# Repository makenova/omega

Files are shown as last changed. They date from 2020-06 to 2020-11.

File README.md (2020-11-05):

# Omega

Hot swap
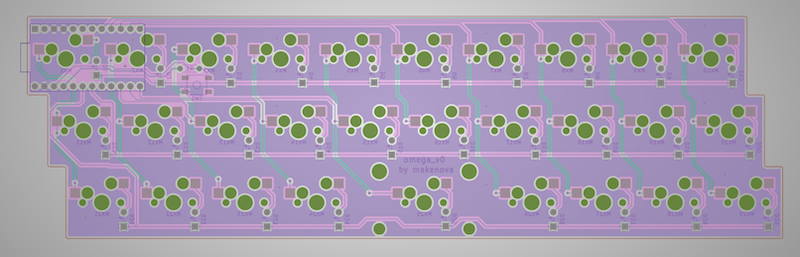
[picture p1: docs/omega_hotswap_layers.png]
tracespace layer


Solder
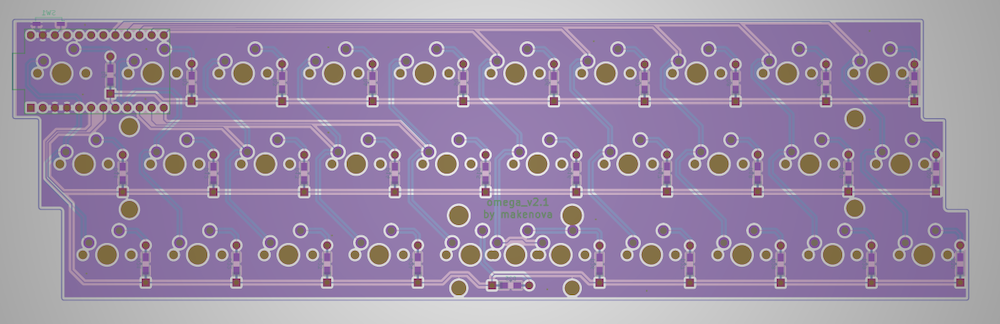
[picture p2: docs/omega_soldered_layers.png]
tracespace layer


Omega4
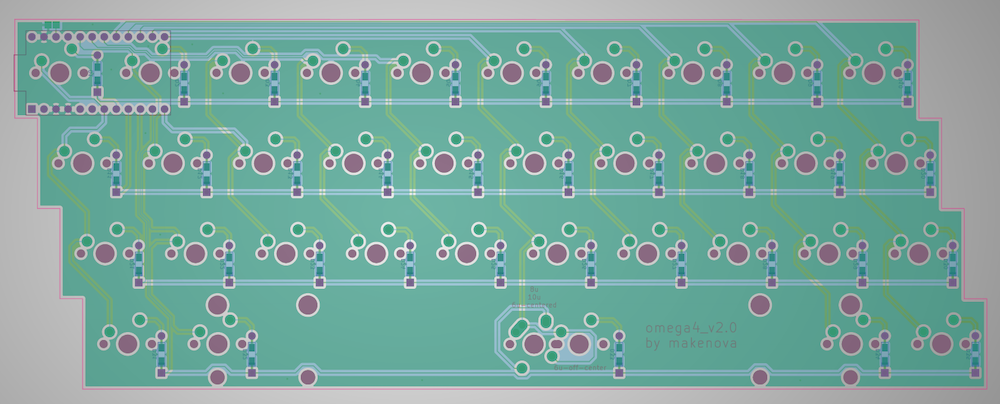
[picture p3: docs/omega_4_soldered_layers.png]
tracespace layer


The omega is a hot swap 30%(30 or 29 keys depending on the layout you choose) inspired by the [Zlant](https://www.reddit.com/r/MechanicalKeyboards/search?q=zlant&restrict_sr=1) and the [Alpha 28](https://geekhack.org/index.php?topic=99040.0) keyboards.  
The omeaga4 adds a 4th with a few options to make this more than a novelty piece.

The plate files, stls for 3D printing, and STEP files can be found in the [docs](./docs) folder.  
There are also gerbers already generated in the gerber folders.

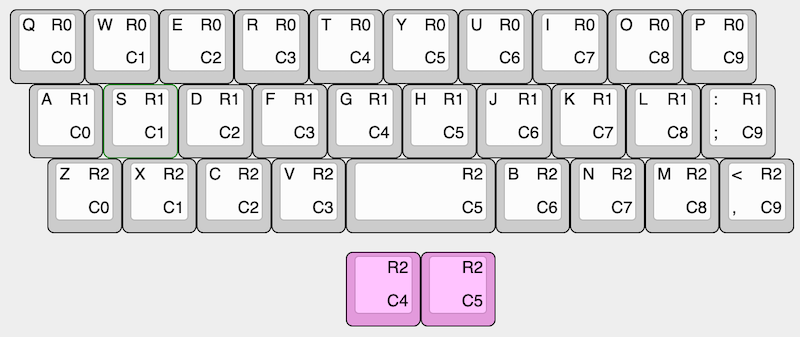
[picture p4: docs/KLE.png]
  
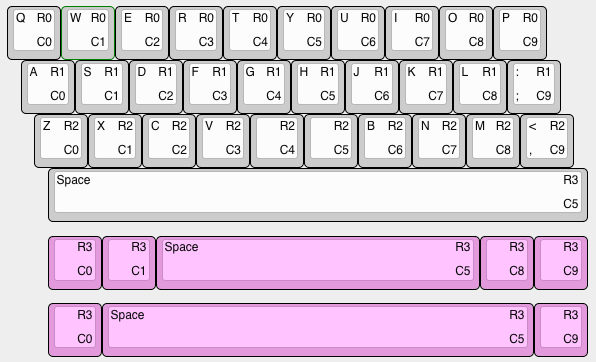
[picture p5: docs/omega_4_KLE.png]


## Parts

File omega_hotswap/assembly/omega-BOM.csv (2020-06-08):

Designator | Quantity | Value | Footprint | LCSC Part #
SW1, | 1 | SW_Push | :SMD-SW-4_5.1x5.1x1.5 | C318884

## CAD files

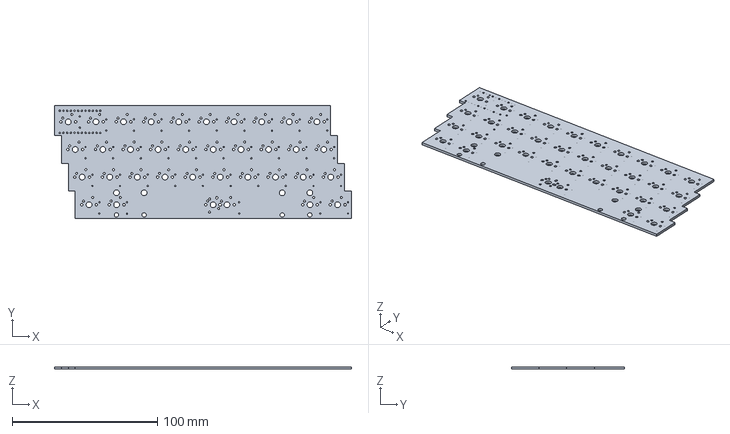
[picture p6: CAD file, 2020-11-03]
docs/omega_4_skeleton_case/omega_4_solder.step
204.8 x 78.0 x 1.60 mm

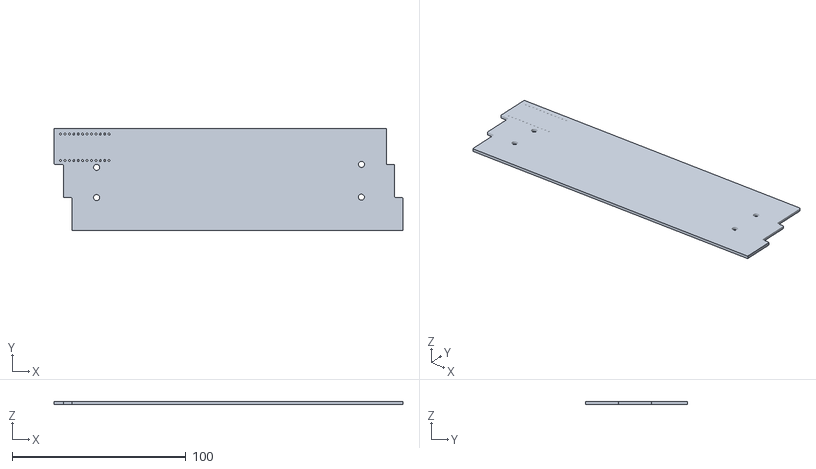
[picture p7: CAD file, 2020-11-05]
docs/omega_skeleton_case/omega_pcb_model.stl
200.8 x 58.9 x 1.60

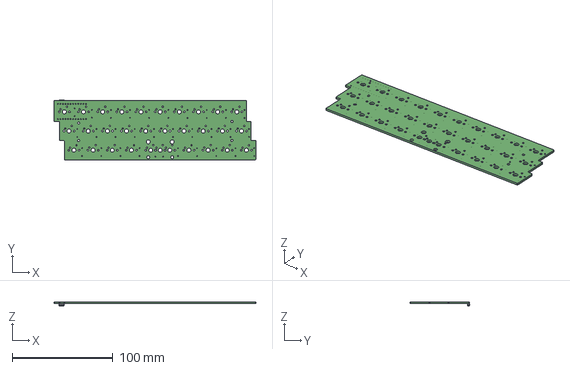
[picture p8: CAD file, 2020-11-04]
docs/omega_solder.step
200.8 x 59.2 x 4.30 mm

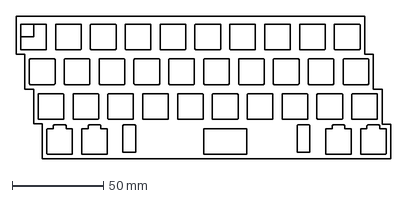
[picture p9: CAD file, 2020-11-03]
docs/omega_4_plate.dxf
204.8 x 78.0 mm

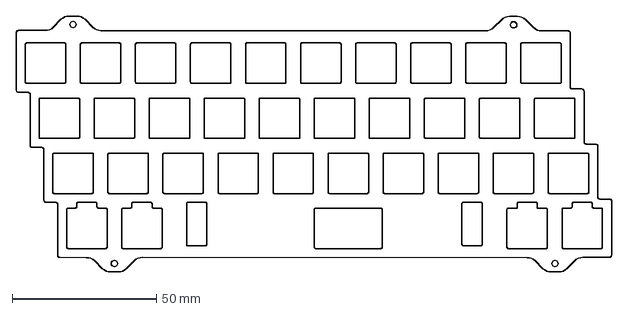
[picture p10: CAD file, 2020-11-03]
docs/omega_4_skeleton_case/omega_4_skeleton_top_plate.dxf
206.0 x 88.6 mm

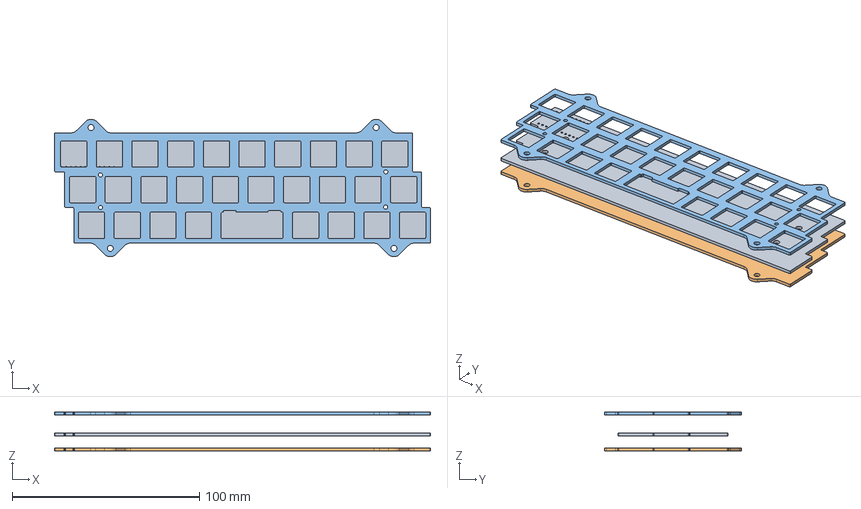
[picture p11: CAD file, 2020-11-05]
docs/omega_skeleton_case/omega_skeleton_case.stp
200.8 x 73.4 x 20.6 mm

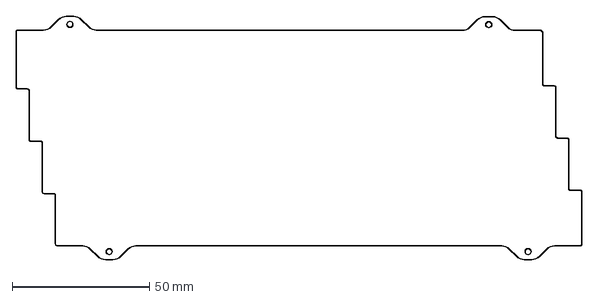
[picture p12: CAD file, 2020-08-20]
docs/omega_4_skeleton_case/omega_4_skeleton_bottom_plate.dxf
206.0 x 88.6 mm

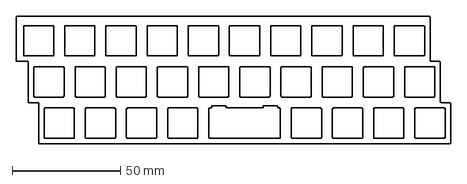
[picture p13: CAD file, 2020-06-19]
docs/plate.dxf
200.8 x 58.9 mm

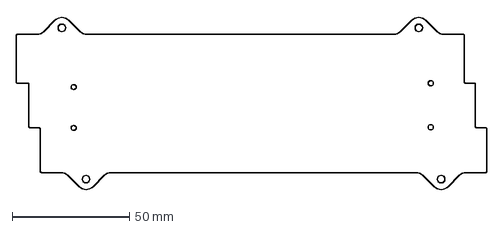
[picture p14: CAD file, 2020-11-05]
docs/omega_skeleton_case/omega_skeleton_bottom_plate.dxf
200.8 x 73.8 mm

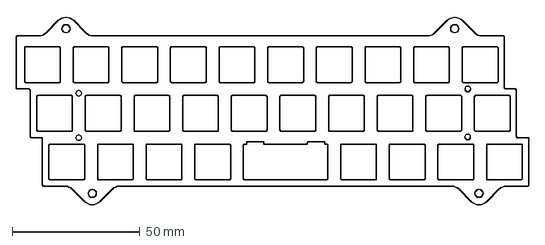
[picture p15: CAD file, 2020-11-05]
docs/omega_skeleton_case/omega_skeleton_top_plate.dxf
200.8 x 73.8 mm

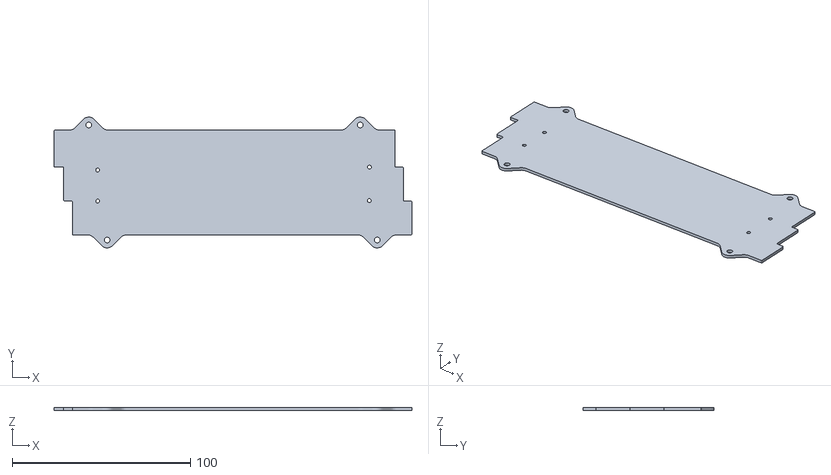
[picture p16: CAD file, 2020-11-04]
docs/omega_skeleton_case/omega_bottom_plate.stl
200.8 x 73.4 x 1.60

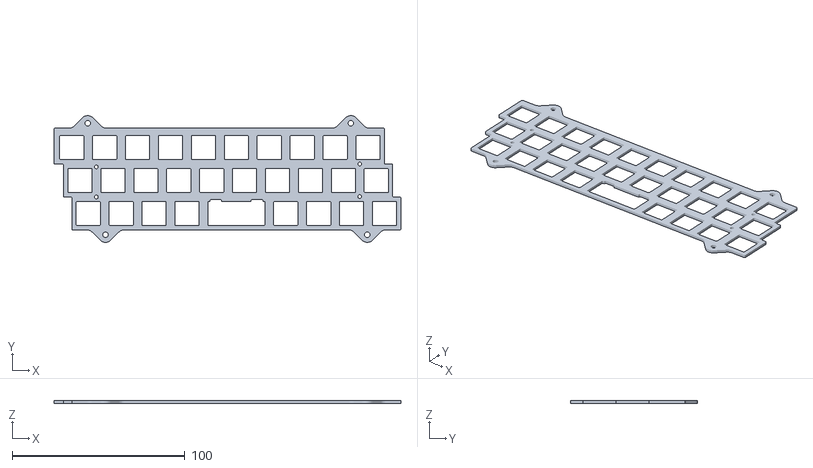
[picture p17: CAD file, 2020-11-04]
docs/omega_skeleton_case/omega_top_plate.stl
200.8 x 73.4 x 1.60

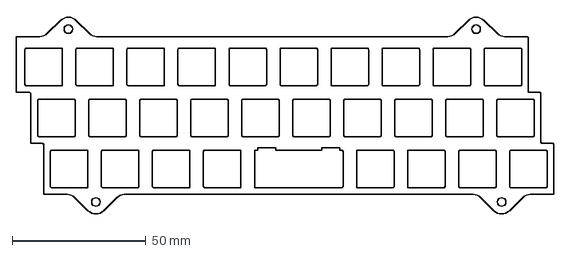
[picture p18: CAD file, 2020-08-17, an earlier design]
docs/omega_skeleton_case/omega_skeleton_top_plate_v0.dxf
200.8 x 73.8 mm

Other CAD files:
docs/omega_skeleton_case/omega_solder.step

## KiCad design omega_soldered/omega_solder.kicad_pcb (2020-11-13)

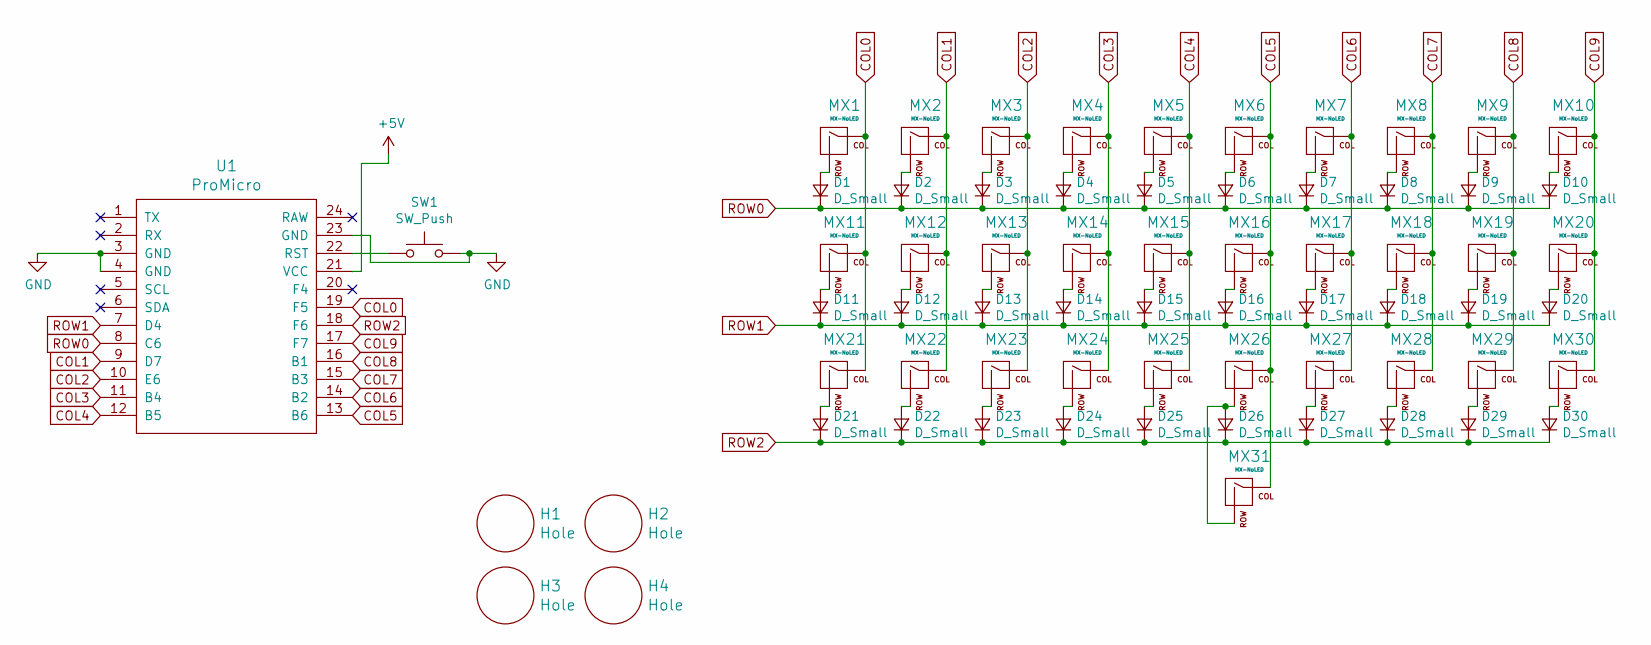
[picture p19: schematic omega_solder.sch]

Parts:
D1, D2, D3, D4, D5, D6, D7, D8, D9, D10, D11, D12, D13, D14, D15, D16, D17, D18, D19, D20, D21, D22, D23, D24, D25, D26, D27, D28, D29, D30: D_Small; Diode-Hybrid-Back
H1, H2, H3, H4: Hole; MountingHole_3.5mm
MX1, MX2, MX3, MX4, MX5, MX6, MX7, MX8, MX9, MX10, MX11, MX12, MX13, MX14, MX15, MX16, MX17, MX18, MX19, MX20, MX21, MX22, MX23, MX24, MX25, MX26, MX27, MX28, MX29, MX30: MX-NoLED; MXOnly-1U-NoLED
MX31: MX-NoLED; MXOnly-2U-ReversedStabilizers-NoLED
SW1: SW_Push; SW_DIP_SPSTx01_Slide_Copal_CHS-01A_W5.08mm_P1.27mm_JPin
U1: ProMicro

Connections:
+5V: U1.21 (VCC)
COL0: MX1.1 (COL), MX11.1 (COL), MX21.1 (COL), U1.19 (F5)
COL1: MX2.1 (COL), MX12.1 (COL), MX22.1 (COL), U1.9 (D7)
COL2: MX3.1 (COL), MX13.1 (COL), MX23.1 (COL), U1.10 (E6)
COL3: MX4.1 (COL), MX14.1 (COL), MX24.1 (COL), U1.11 (B4)
COL4: MX5.1 (COL), MX15.1 (COL), MX25.1 (COL), U1.12 (B5)
COL5: MX6.1 (COL), MX16.1 (COL), MX26.1 (COL), MX31.1 (COL), U1.13 (B6)
COL6: MX7.1 (COL), MX17.1 (COL), MX27.1 (COL), U1.14 (B2)
COL7: MX8.1 (COL), MX18.1 (COL), MX28.1 (COL), U1.15 (B3)
COL8: MX9.1 (COL), MX19.1 (COL), MX29.1 (COL), U1.16 (B1)
COL9: MX10.1 (COL), MX20.1 (COL), MX30.1 (COL), U1.17 (F7)
GND: SW1.2, U1.3 (GND), U1.4 (GND), U1.23 (GND)
unnamed: D1.2 (A), MX1.2 (ROW)
unnamed: D2.2 (A), MX2.2 (ROW)
unnamed: D3.2 (A), MX3.2 (ROW)
unnamed: D4.2 (A), MX4.2 (ROW)
unnamed: D5.2 (A), MX5.2 (ROW)
unnamed: D6.2 (A), MX6.2 (ROW)
unnamed: D7.2 (A), MX7.2 (ROW)
unnamed: D8.2 (A), MX8.2 (ROW)
unnamed: D9.2 (A), MX9.2 (ROW)
unnamed: D10.2 (A), MX10.2 (ROW)
unnamed: D11.2 (A), MX11.2 (ROW)
unnamed: D12.2 (A), MX12.2 (ROW)
unnamed: D13.2 (A), MX13.2 (ROW)
unnamed: D14.2 (A), MX14.2 (ROW)
unnamed: D15.2 (A), MX15.2 (ROW)
unnamed: D16.2 (A), MX16.2 (ROW)
unnamed: D17.2 (A), MX17.2 (ROW)
unnamed: D18.2 (A), MX18.2 (ROW)
unnamed: D19.2 (A), MX19.2 (ROW)
unnamed: D20.2 (A), MX20.2 (ROW)
unnamed: D21.2 (A), MX21.2 (ROW)
unnamed: D22.2 (A), MX22.2 (ROW)
unnamed: D23.2 (A), MX23.2 (ROW)
unnamed: D24.2 (A), MX24.2 (ROW)
unnamed: D25.2 (A), MX25.2 (ROW)
unnamed: D26.2 (A), MX26.2 (ROW), MX31.2 (ROW)
unnamed: D27.2 (A), MX27.2 (ROW)
unnamed: D28.2 (A), MX28.2 (ROW)
unnamed: D29.2 (A), MX29.2 (ROW)
unnamed: D30.2 (A), MX30.2 (ROW)
unnamed: SW1.1, U1.22 (RST)
ROW0: D1.1 (K), D2.1 (K), D3.1 (K), D4.1 (K), D5.1 (K), D6.1 (K), D7.1 (K), D8.1 (K), D9.1 (K), D10.1 (K), U1.8 (C6)
ROW1: D11.1 (K), D12.1 (K), D13.1 (K), D14.1 (K), D15.1 (K), D16.1 (K), D17.1 (K), D18.1 (K), D19.1 (K), D20.1 (K), U1.7 (D4)
ROW2: D21.1 (K), D22.1 (K), D23.1 (K), D24.1 (K), D25.1 (K), D26.1 (K), D27.1 (K), D28.1 (K), D29.1 (K), D30.1 (K), U1.18 (F6)

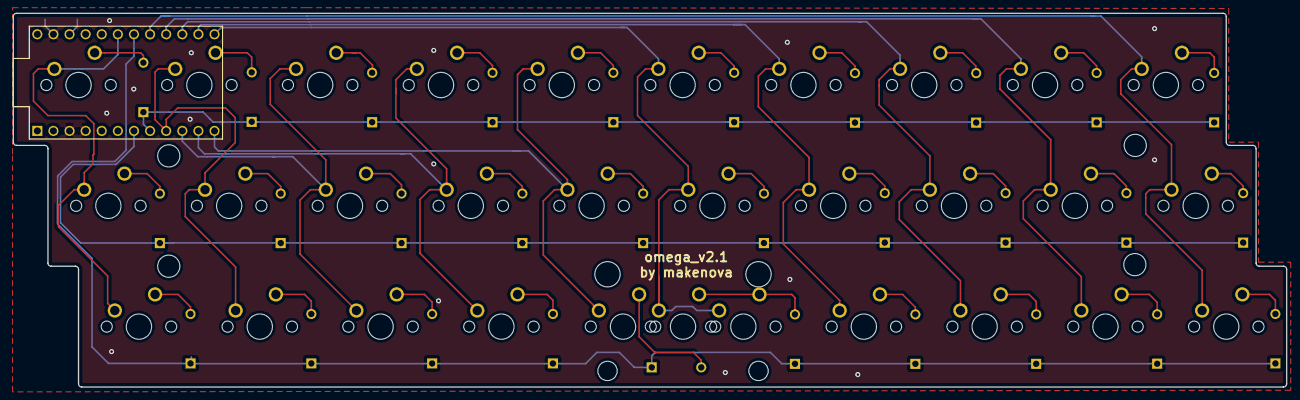
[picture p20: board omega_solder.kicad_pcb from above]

Board: 2 copper layers, 200.8 x 58.9 mm, 67 parts (1 on the bottom side), 45 nets.

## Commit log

2020-06-01 make it so
    add libraries
    set up schematic
    layout pcb components
    begin routing
    [omega.kicad_pcb, omega.sch, plate-20200531-121810.dxf]
2020-06-01 generate gerber for tracespace
    [omega-B_Cu.gbr, omega-B_Mask.gbr, omega-B_SilkS.gbr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]
2020-06-08 flip pro micor and generate assembly files
    [omega-BOM.csv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]
2020-06-16 separate hot swap and soldered version
    [omega-BOM.csv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]
2020-06-19 add solder version
    [omega.kicad_pcb, omega.step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]
2020-06-19 update docs and plate
    [omega.step, plate-20200531-121810.dxf, plate.dxf]
2020-08-13 add: omega_4
    [omega_4_plate.dxf, omega_4_plate_clean.dxf, omega_4_solder.kicad_pcb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]
2020-08-17 generate production files
    [omega_4_plate_clean_1.dxf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]
2020-08-17 add jumper to skeleton case
    jumper get the solder mask to show up
    [omega_4_skeleton_bottom-B_Cu.gbr, omega_4_skeleton_bottom-B_Mask.gbr, omega_4_skeleton_bottom-B_Paste.gbr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]
2020-08-18 update skeleton top plate
    remove acoustic cuts and round off 90 degree angles
    [omega_4_skeleton_top-B_Cu.gbr, omega_4_skeleton_top-B_Mask.gbr, omega_4_skeleton_top-B_Paste.gbr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]
2020-08-20 update skeleton case to allow 3mm between cuts and regen prod files
    [omega_4_skeleton_bottom-B_Cu.gbr, omega_4_skeleton_bottom-B_Mask.gbr, omega_4_skeleton_bottom-B_Paste.gbr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]
2020-11-03 update spacebars on omega4
    fix spacebar positioning on omega4
    [omega_4_solder.kicad_pcb, omega_4_solder.sch]
2020-11-03 update omega4 case files
    move stabilizer cutouts
    [omega_4_plate.dxf, omega_4_plate_clean.dxf, omega_4_plate_clean_1.dxf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]
2020-11-04 update soldered omega
    flip pro micro footprint
    shuffle mounting holes
    make stl files to 3D print for testing
    regenerate gerbers
    [omega_bottom_plate.stl, omega_pcb_model.stl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]
2020-11-05 update soldered omega
    increase stanoff hole size through the pcb
    update stl files and step files
    shuffle file locations
    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
    [omega.step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]
2020-11-13 do not use series pins on omega soldered
    regenerage gerber files for omega soldered and omega 4
    [omega_4_solder-B_Cu.gbr, omega_4_solder-B_Mask.gbr, omega_4_solder-B_Paste.gbr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]
